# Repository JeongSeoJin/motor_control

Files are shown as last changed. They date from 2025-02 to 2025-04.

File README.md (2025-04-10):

# motor_control

## This repository for motor control and Actuators 
foc control, simplefoc, position control, impedance control and so on

Actuator_V2 folder is complete opensource for proprioceptive actuator. there's a source code for motor control, step files, elements for complete building.

And I am going to make some youtube video for Building Tutorials and specific sources about my own proprioceptive acutator. you can expect it!

Actuator V2 preview is below

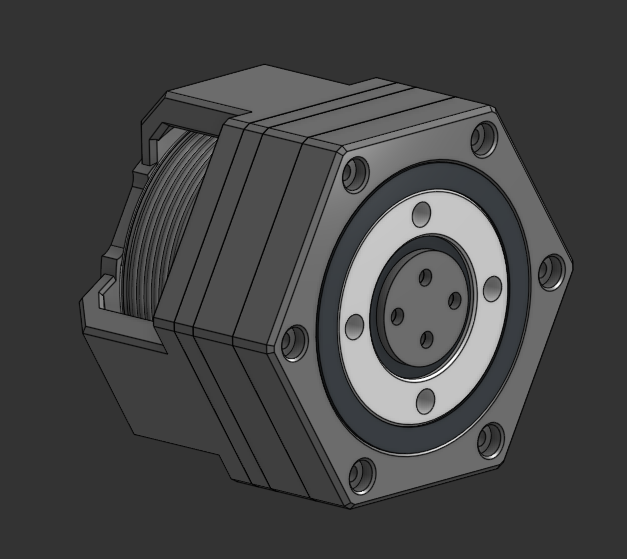
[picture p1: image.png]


And 'drv8302_sunnysky_impedance_arduino' and 'drv8302_sunnysky_impedance_esp' are not actually torque control with current. This is based on voltage systemically. The actual Impedance Control(Torque Control) is 'esp32_current_control_low_side'. This is the Torque Control(Q-axis Current Control) with FOC Algorithm. 

'master_two_drv8302_control_with_CAN', 'slave_two_drv8302_control_with_CAN' and 'two_drv8302_control_with_CAN' are motor control which is 'esp32_current_control_low_side' merged with ACAN library.

By the way, 'TWAI_Simplefoc_Node' is motor control which is 'esp32_current_control_low_side' merged with ESP32-TWAI-CAN library.

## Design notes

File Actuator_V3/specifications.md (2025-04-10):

# Proprioceptive Actuator V2 Specification
---

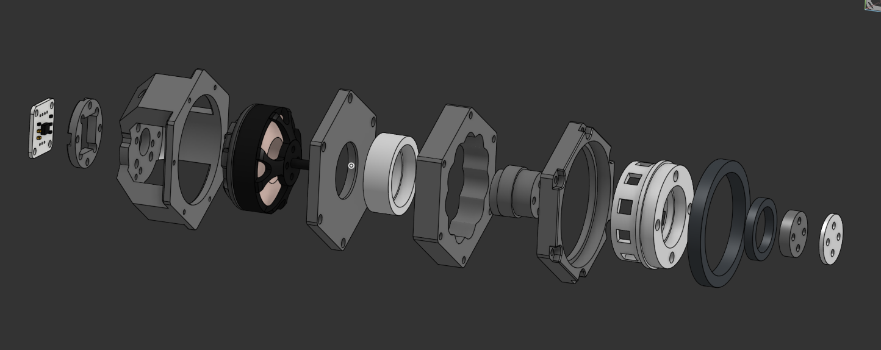
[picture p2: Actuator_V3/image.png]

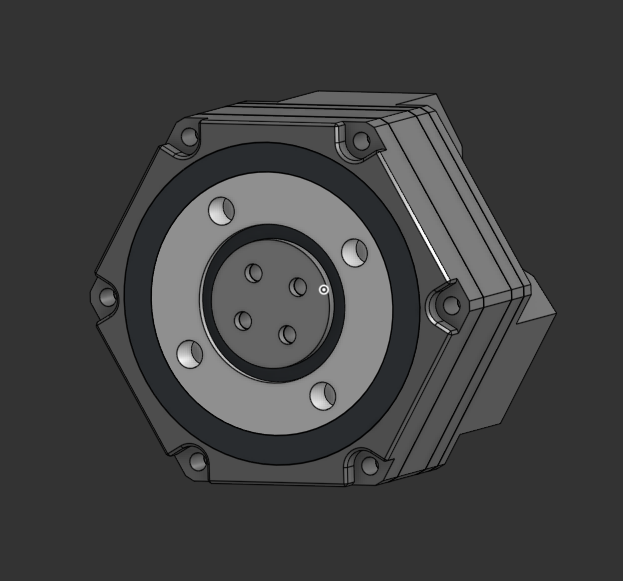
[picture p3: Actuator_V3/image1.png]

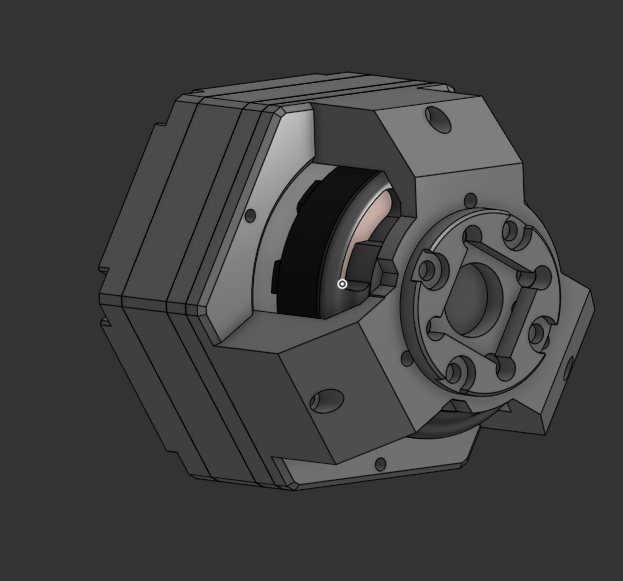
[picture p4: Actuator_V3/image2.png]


## Ball-Element Cycloidal drive actuator V2 (High Performance)
- bldc motor : Gartt ML5210 bldc motor(1EA): [sunnysky x4108s-17 bldc motor](https://ko.aliexpress.com/item/4001297326582.html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)
- motor driver : drv8302(1EA) : [drv8302 driver](https://ko.aliexpress.com/item/4000126430773.html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)
- microcontroller : ESP-wroom-32(1EA) : [ESP-wroom-32](https://ko.aliexpress.com/item/1005007050459447.html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)
- encoder : AS5600(1EA) : [AS5600](https://ko.aliexpress.com/item/1005006502384626.html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)
- For CAN BUS : TJA1051T(1EA) : [TJA1051T](https://ko.aliexpress.com/item/1005007053249619.html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)
- gear box : 3d printed gearbox
- ball-elements(10EA) : [M6x6mm ball-elements](https://ko.aliexpress.com/item/1005003729421711.html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)
- M3x30mm bolts(4EA) : [M3x30mm bolts](https://ko.aliexpress.com/item/1005005879037174.html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)
- M3x20mm bolts(6EA) : [M3x20mm bolts](https://ko.aliexpress.com/item/1005005879037174.html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)
- M2x10mm bolts(6EA) : [M2x10mm bolts]()
- M2x3mm insert nuts(6EA) : [M2x3mm insert nuts](https://ko.aliexpress.com/item/1005004870993068.html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)
- M3x3mm insert nuts(6EA) : [M3x3mm insert nuts](https://ko.aliexpress.com/item/1005004870993068.html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)
- M3x6mm insert nuts(6EA) : [M3x6mm insert nuts](https://ko.aliexpress.com/item/1005004870993068.html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)
- 20x27x4 bearings(3EA) : [20x27x4 bearings](https://ko.aliexpress.com/item/1005006822777675.html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)
- 45x55x6mm bearings(1EA) : [45x55x6mm bearings](https://ko.aliexpress.com/item/4000909605390.html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)

you can see more specific code at [simplefoc documents](https://docs.simplefoc.com/code)

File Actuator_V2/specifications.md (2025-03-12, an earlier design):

# Proprioceptive Actuator V2 Specification
---

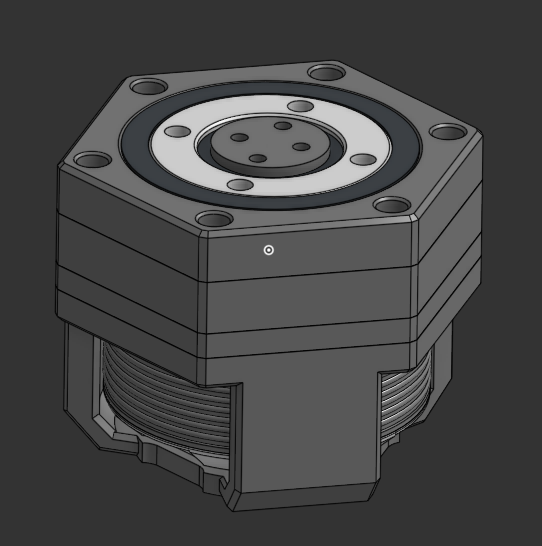
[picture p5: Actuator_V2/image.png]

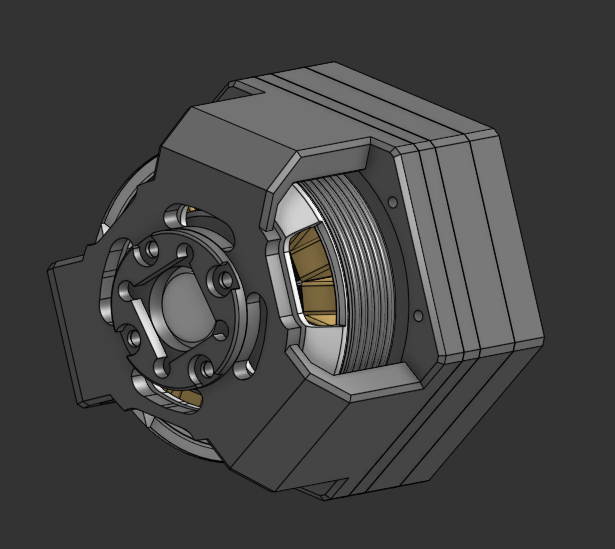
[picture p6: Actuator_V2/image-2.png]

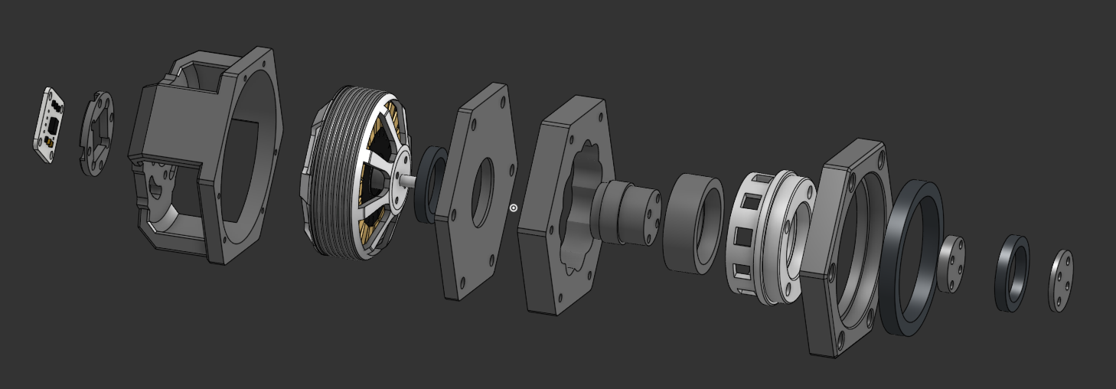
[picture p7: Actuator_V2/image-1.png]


## Ball-Element Cycloidal drive actuator V2 (High Performance)
- bldc motor : Gartt ML5210 bldc motor(1EA): [gartt-ML5210 motor](https://ko.aliexpress.com/item/4001297326582.html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)
- motor driver : drv8302(1EA) : [drv8302 driver](https://ko.aliexpress.com/item/4000126430773.html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)
- microcontroller : ESP-wroom-32(1EA) : [ESP-wroom-32](https://ko.aliexpress.com/item/1005007050459447.html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)
- encoder : AS5600(1EA) : [AS5600](https://ko.aliexpress.com/item/1005006502384626.html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)
- For CAN BUS : TJA1051T(1EA) : [TJA1051T](https://ko.aliexpress.com/item/1005007053249619.html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)
- gear box : 3d printed gearbox
- ball-elements(10EA) : [M6x6mm ball-elements](https://ko.aliexpress.com/item/1005003729421711.html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)
- M3x30mm bolts(4EA) : [M3x30mm bolts](https://ko.aliexpress.com/item/1005005879037174.html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)
- M3x20mm bolts(6EA) : [M3x20mm bolts](https://ko.aliexpress.com/item/1005005879037174.html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)
- M2x10mm bolts(6EA) : [M2x10mm bolts]()
- M2x3mm insert nuts(6EA) : [M2x3mm insert nuts](https://ko.aliexpress.com/item/1005004870993068.html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)
- M3x3mm insert nuts(6EA) : [M3x3mm insert nuts](https://ko.aliexpress.com/item/1005004870993068.html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)
- M3x6mm insert nuts(6EA) : [M3x6mm insert nuts](https://ko.aliexpress.com/item/1005004870993068.html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)
- 20x27x4 bearings(3EA) : [20x27x4 bearings](https://ko.aliexpress.com/item/1005006822777675.html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)
- 45x55x6mm bearings(1EA) : [45x55x6mm bearings](https://ko.aliexpress.com/item/4000909605390.html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)

you can see more specific code at [simplefoc documents](https://docs.simplefoc.com/code)

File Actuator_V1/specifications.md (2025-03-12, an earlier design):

# Actuator V1 Specification
---

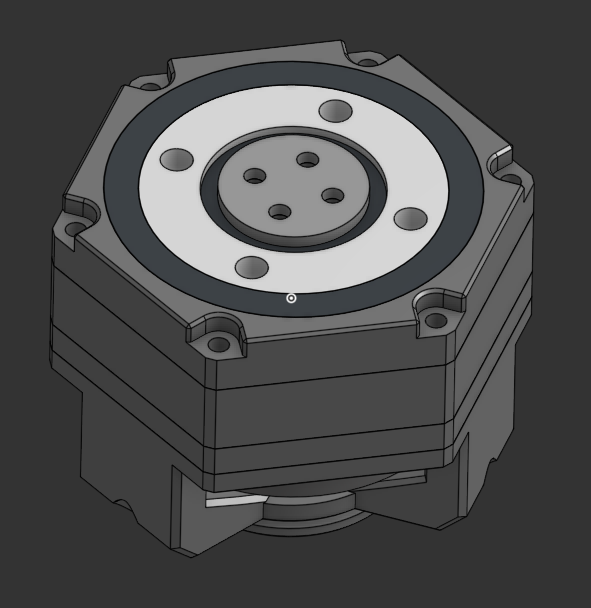
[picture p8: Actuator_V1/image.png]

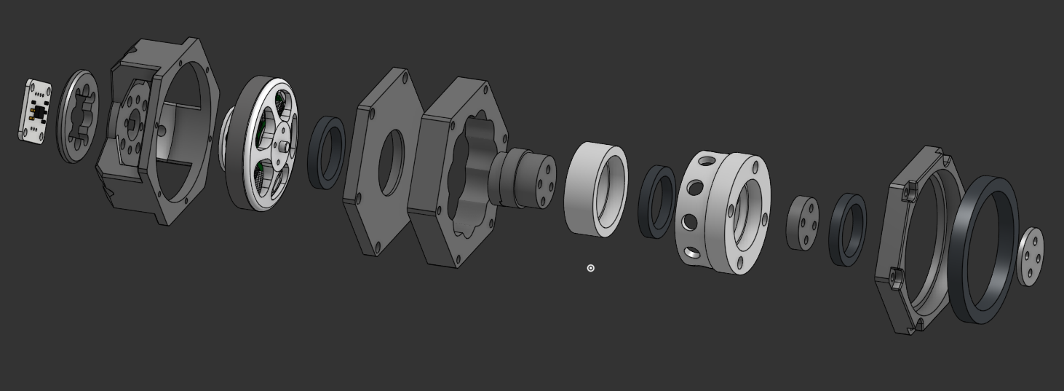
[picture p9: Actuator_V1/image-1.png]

## Ball-Element Cycloidal drive actuator V1
- bldc motor : 5010 bldc motor : [5010 bldc motor](https://ko.aliexpress.com/item/32479766898.html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)
- motor driver : simplefoc v2 : [simplefoc v2](https://simplefoc.com/simplefoc_shield_product)
- microcontroller : arduino uno
- encoder : AS5600 : [AS5600](https://ko.aliexpress.com/item/1005006502384626.html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)
- For CAN BUS : None
- gear box : 3d printed gearbox

you can see more specific code at [simplefoc documents](https://docs.simplefoc.com/code)

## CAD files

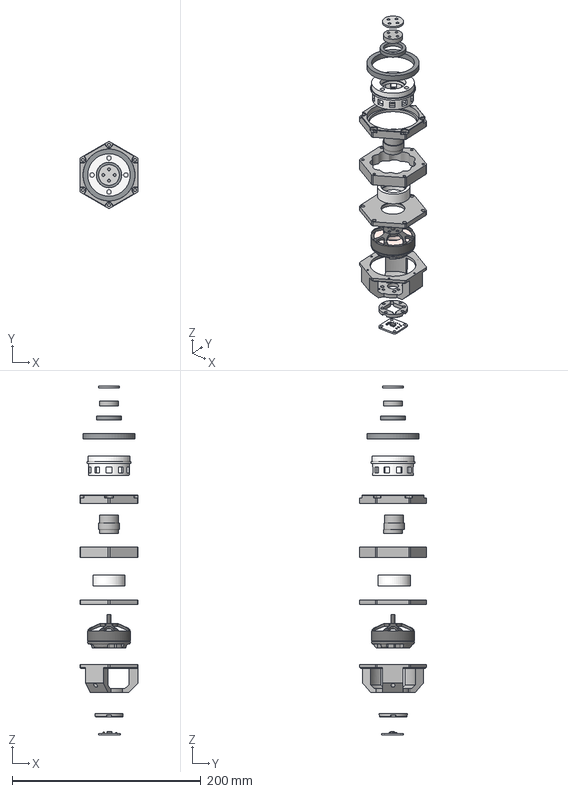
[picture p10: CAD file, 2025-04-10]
Actuator_V3/Actuator_V3_assembly_file.step
62.0 x 70.6 x 370.2 mm
motor_cover
body_middle
Rotor
body_bottom
cam_middle
cam_cover
body_top
AS5600 v1
Stator
bearing_huge
cam_bottom
bearing
wave_generator
separator
Coils

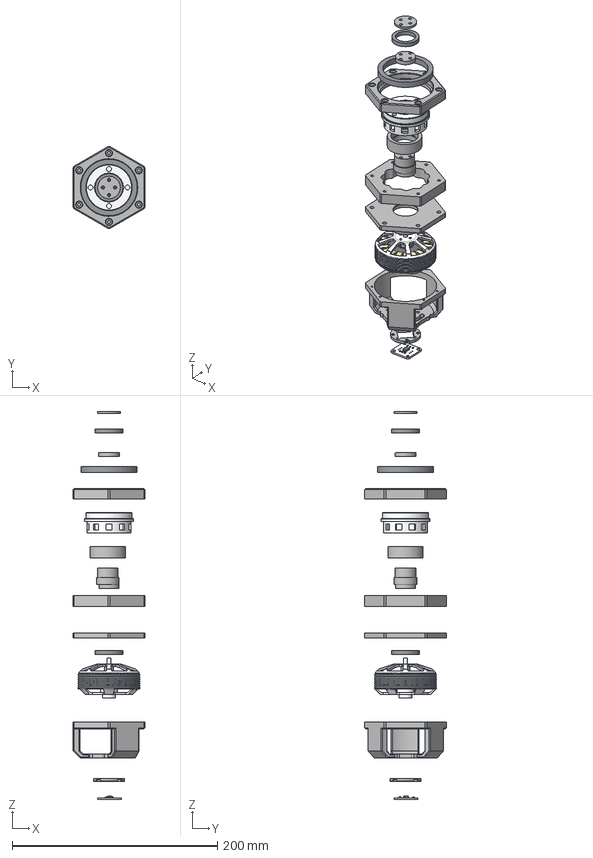
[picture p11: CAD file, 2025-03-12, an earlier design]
Actuator_V2/Actuator_V2_assembly_file.step
70.0 x 79.8 x 377.9 mm
bearing_huge
bearing x 2
mount
cam_bottom
stator
rotor
cam_middle
body_middle
bldc_cover
AS5600 v1
cam_cover
wave_generator
body_bottom
body_top
separator

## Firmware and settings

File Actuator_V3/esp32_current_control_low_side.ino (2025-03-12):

/**
 * 위치 기반 토크 제어 (전류제어 FOC) 예시 코드
 * 
 * [개념]
 *  - 모터의 현재 각도(shaft_angle, [rad])와 목표 각도(theta_desired, [rad])를 비교해
 *    오차(angleError)를 구한다.
 *  - 오차 * Kp ([A/rad]) = 토크 지령 전류(I_q_ref, [A])를 계산한다.
 *  - SimpleFOC는 FOC Current 모드(TorqueControlType::foc_current)에서 이 전류를
 *    실제로 모터의 q축 전류(I_q)로 만들기 위해 PWM을 제어한다.
 * 
 *  => motor.target = I_q_ref (단위: [A])
 *  => 실제 토크 T [N·m] = Kt [N·m/A] × I_q [A]
 */

// This source code is for a proprioceptive actuator v2. torque sensing using q-axis current sensing

#include <SimpleFOC.h>  // SimpleFOC 라이브러리
#include <math.h>

// ============================ 핀 매핑 설정 ============================
// DRV8302 보드 핀 연결 (기본 예시)
#define INH_A    14     // 하이사이드 PWM A
#define INH_B    27     // 하이사이드 PWM B
#define INH_C    26     // 하이사이드 PWM C
#define EN_GATE  13     // 드라이버 활성화
#define M_PWM    33     // 3pwm 모드 설정
#define M_OC     25     // 오버커런트 보호
#define OC_ADJ   32     // 오버커런트 조정
#define OC_GAIN  5      // DRV8302 내부 증폭기 게인 선택 핀

// 로사이드 전류 센싱 핀 (ESP32 ADC 핀)
#define IOUTA 4         // ADC2_CH0
#define IOUTB 12        // ADC2_CH5
#define IOUTC 15        // ADC2_CH3

// ============================= 모터, 드라이버, 센서 =============================

// 1) 모터 객체
//  - BLDCMotor( pole_pairs ): pole_pairs = 극수(pole) / 2
//  - 예: 22극 모터 -> pole_pairs=11
BLDCMotor motor = BLDCMotor(11);

// 2) 드라이버 객체
BLDCDriver3PWM driver = BLDCDriver3PWM(INH_A, INH_B, INH_C, EN_GATE);

// 3) 로사이드 전류센싱
//  - 샨트저항: 0.005Ω
//  - 증폭기 게인: 12.22 V/V (DRV8302 내부 증폭 + 외부 회로에 따라 측정)
LowsideCurrentSense cs = LowsideCurrentSense(0.005f, 12.22f, IOUTA, IOUTB, IOUTC);

// 4) 엔코더 (AS5600 I2C 예시)
MagneticSensorI2C encoder = MagneticSensorI2C(AS5600_I2C);

// 5) 시리얼 커맨드 인터페이스
Commander command = Commander(Serial);
// void onMotor(char* cmd) { command.motor(&motor, cmd); }

// ============================= 제어용 전역 변수 =============================
// 목표 각도 [rad]
float theta_desired = 0.0f;  
// 위치 오차 → 전류로 바꿀 때 사용하는 비례이득 Kp [A/rad]
// 예) Kp=1.0 -> 오차 1rad당 q축전류 1A
float Kp = 2.0f; // max : 5.0
float Cd = 0.2f; // max : 0.2
float max_speed = 60.0f;

float Kt = 60 / (2 * PI * 380);

// Commander에서 theta_desired, Kp를 설정하기 위한 함수
void doRefAngle(char* cmd) { command.scalar(&theta_desired, cmd); }
void doKp(char* cmd)       { command.scalar(&Kp, cmd); }
void doCd(char* cmd)       { command.scalar(&Cd, cmd); }

void setup() {
  // ========== 시리얼 초기화 ==========
  Serial.begin(115200);
  // SimpleFOC 디버그 활성화(옵션)
  SimpleFOCDebug::enable(&Serial);

  // ========== 센서 초기화 ==========
  encoder.init();           // I2C 기반 AS5600 초기화
  motor.linkSensor(&encoder);

  // ========== DRV8302 관련 핀 설정 ==========
  pinMode(M_OC, OUTPUT);
  digitalWrite(M_OC, LOW);
  pinMode(M_PWM, OUTPUT);
  digitalWrite(M_PWM, HIGH);
  pinMode(OC_ADJ, OUTPUT);
  digitalWrite(OC_ADJ, HIGH);
  pinMode(OC_GAIN, OUTPUT);
  digitalWrite(OC_GAIN, LOW); // LOW 상태에서 특정 게인 (약 10~12배)

  // ========== 드라이버 설정 ==========
  driver.voltage_power_supply = 30;   // 드라이버 공급전압 [V]
  driver.pwm_frequency = 15000;       // PWM 주파수 [Hz]
  driver.init();
  motor.linkDriver(&driver);

  // ========== 전류센서 설정 ==========
  cs.linkDriver(&driver);
  
  // ========== 모터 기본 파라미터 ==========
  // FOC 정렬 시 사용하는 전압(각도 캘리브레이션)
  motor.voltage_sensor_align = 0.5f; // [V]
  
  // ========== 핵심: 전류제어(FOC) 설정 ==========
  // 1) 토크제어 모드: foc_current => q축 전류를 직접 제어함
  motor.torque_controller = TorqueControlType::foc_current;
  
  // 2) MotionControlType::torque => motor.target = q축전류(A)
  motor.controller = MotionControlType::torque;
  
  // 3) motion_downsample: 속도/각도 루프를 생략하거나 간소화 (여기서는 0.0)
  motor.motion_downsample = 0.0;

  // ========== PID / LPF 설정 (주로 내부 PI 전류 루프) ==========
  // 전류 i_q 제어
  motor.PID_current_q.P  = 0.05f;   // [V/A] (내부 환산 게인)
  motor.PID_current_q.I  = 0.6f; // [V/(A·s)]
  motor.LPF_current_q.Tf = 0.04f;  // [s]

  // 전류 i_d 제어
  motor.PID_current_d.P  = 0.05f;   // [V/A]
  motor.PID_current_d.I  = 0.6f; // [V/(A·s)]
  motor.LPF_current_d.Tf = 0.04f;  // [s]

  // 속도/각도 제어(지금 안씀)도 일단 기본값 설정
  motor.PID_velocity.P  = 0.1f; 
  motor.PID_velocity.I  = 1.7f;  
  motor.LPF_velocity.Tf = 0.001f;
  motor.P_angle.P       = 10.0f;  
  motor.LPF_angle.Tf    = 0.0f;

  // ========== 제한값 ==========
  // 최대 속도 [rad/s] (토크모드이지만 안전 차원)
  motor.velocity_limit = 50.0f; 
  // FOC에서 인가할 전압의 최대치 [V]
  motor.voltage_limit  = 20.0f;  
  // 최대 전류 제한 [A]
  // -> motor.target이 이 값을 초과 못하도록 내부 보호
  motor.current_limit  = 13.0f;   

  // ========== 모니터링 설정 ==========
  motor.useMonitoring(Serial);
  // D축, Q축 전류 모니터링
  motor.monitor_variables = _MON_CURR_Q | _MON_CURR_D; // q가 토크에 관여, D는 0에 가까워져 있어야함. 
  // 출력 주기 : loopFOC()가 n번 실행될 때마다 한번씩 출력
  motor.monitor_downsample = 100;

  // ========== 모터 초기화 ==========
  motor.init();   // 드라이버, 센서 설정에 맞춰 모터구조 초기 설정
  cs.init();      // 전류센싱 초기화
  // DRV8302는 내부적으로 게인이 반전돼있는 경우가 있어 -1 곱
  cs.gain_a *= -1;
  cs.gain_b *= -1;
  cs.gain_c *= -1;
  motor.linkCurrentSense(&cs);

  // ========== FOC align & start ==========
  // 실제 모터에 전압을 인가하여 엔코더 0점 찾고, d/q 축 정렬
  motor.initFOC();

  // ========== Commander (시리얼 명령) ==========
  // command.add('M', onMotor, "motor");
  command.add('R', doRefAngle, "ref angle [rad]");
  command.add('K', doKp, "Kp [A/rad]");
  command.add('C', doCd, "Cd [A/rad]");

  Serial.println(F("FOC Current-based Torque Control (Position-based)"));
  Serial.println(F(" - R: set target angle [rad]"));
  Serial.println(F(" - K: set Kp [A/rad] (proportional gain)"));
  Serial.println(F(" motor.target will be I_q [A] in torque mode.\n"));

  _delay(1000);
}

void loop() {
  // ========== 1) FOC 알고리즘 업데이트 ==========
  //   - 센서 위치 갱신, d/q 전류 측정 및 PID 계산 등
  motor.loopFOC();

  // ========== 2) 위치 오차 계산 ==========
  //   - 엔코더 각도 [rad]
  float theta = motor.shaft_angle;
  float dtheta = motor.shaft_velocity;
  //   - theta_desired [rad], currentAngle [rad]
  // float angleError = theta_desired - currentAngle;  // [rad]

  // ========== 3) 토크 전류 지령 (Iq_ref) 계산 ==========
  //   - Kp [A/rad] * angleError [rad] = Iq_ref [A]
  float Iq_ref = Kp * (theta_desired - theta) -Cd * dtheta;

  // ========== 4) 모터에 q축 전류 지령 전송 ==========
  //   - torque 모드이므로 motor.target = Iq_ref
  //   - motor.target 단위: [A]

  float output_torque = 10 * Kt * motor.current.q;
  // Serial.println(output_torque);
  // Serial.println(motor.current.q); // 실제 q축 전류

  motor.target = Iq_ref; // [A] foc_current제어이기 때문에 target값이 q축 전류이다.

  // ========== 5) FOC 업데이트 (PWM 출력) ==========
  motor.move();

  // ========== 6) 모니터링 ==========
  motor.monitor();

  // ========== 7) 시리얼 명령 처리 ==========
  command.run();
}

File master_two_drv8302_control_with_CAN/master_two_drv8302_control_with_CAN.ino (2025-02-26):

/********************************************************
 * 1) 매크로 설정: 마스터 / 슬레이브 선택
 ********************************************************/
#define IS_MASTER  // <- 주석 해제 시, 이 보드는 마스터(Commander로 파라미터 입력 + CAN 전송)
//#define IS_MASTER  // 주석 처리 시, 슬레이브(직렬 Commander 없음, CAN 수신만)


/********************************************************
 * 2) 헤더 선언
 ********************************************************/
#include <ACAN_ESP32.h>      // CAN 통신 라이브러리
#include <SimpleFOC.h>       // 모터 FOC 라이브러리
#include <math.h>


/********************************************************
 * 3) CAN 통신 관련 상수
 ********************************************************/
// 원하는 CAN 속도 (예시: 500 kbps)
static const uint32_t DESIRED_BIT_RATE = 500UL * 1000UL;

// CAN 메시지 전송 주기를 제어할 수도 있지만
// 여기서는 "파라미터가 바뀔 때" 즉시 전송하는 방식을 시연

// LED 핀 (ESP32 일부 보드는 2번이 내장 LED)
static const int LED_PIN = 2;

/********************************************************
 * 4) SimpleFOC 모터, 드라이버, 센서 설정
 ********************************************************/
// drv8302 + esp-wroom-32
#define INH_A    14     // 하이사이드 PWM A
#define INH_B    27     // 하이사이드 PWM B
#define INH_C    26     // 하이사이드 PWM C
#define EN_GATE  13     // 드라이버 활성화
#define M_PWM    33     // 3pwm 모드 설정
#define M_OC     25     // 오버커런트 보호
#define OC_ADJ   32     // 오버커런트 조정
#define OC_GAIN  5      // DRV8302 내부 증폭기 게인 선택 핀

// 로사이드 전류 센싱 핀 (ESP32 ADC 핀)
#define IOUTA 4         // ADC2_CH0
#define IOUTB 12        // ADC2_CH5
#define IOUTC 15        // ADC2_CH3

BLDCMotor motor(11);                            // Pole pairs=11 예시
BLDCDriver3PWM driver(INH_A, INH_B, INH_C, EN_GATE);
MagneticSensorI2C encoder(AS5600_I2C);
LowsideCurrentSense cs = LowsideCurrentSense(0.005f, 12.22f, IOUTA, IOUTB, IOUTC);

float theta_desired = 0.0f;  
float Kp = 2.0f; // max : 5.0
float Cd = 0.2f; // max : 0.2
float max_speed = 60.0f;
float Kt = 60 / (2 * PI * 380);


/********************************************************
 * 5) Commander: 직렬 명령 파싱 (마스터에서만 사용)
 ********************************************************/
#ifdef IS_MASTER
// #include <SimpleFOCCommander.h>
Commander command = Commander(Serial);

// FOC 모터에 대한 콜백
// void onMotor(char* cmd) { command.motor(&motor, cmd); }
void setVelocityP(char* cmd) { command.scalar(&motor.PID_velocity.P, cmd); }
void setVelocityI(char* cmd) { command.scalar(&motor.PID_velocity.I, cmd); }
#endif

/********************************************************
 * 6) 임피던스 제어용 파라미터
 ********************************************************/
// (필요하면 M_mass, target_position 등 추가 가능)

/********************************************************
 * 7) 전역 변수 / 자료형
 ********************************************************/
// float ↔ byte 변환용 union
union FloatUnion {
  float f;
  uint8_t b[4];
};

// 파라미터 식별자
static const uint8_t PARAM_ID_REF_ANGLE = 0x01;
static const uint8_t PARAM_ID_KSPRING   = 0x02;
static const uint8_t PARAM_ID_CDAMPER   = 0x03;

// CAN ID (파라미터 브로드캐스트용)
static const uint32_t PARAM_CAN_ID = 0x100;

/********************************************************
 * 8) 파라미터 변경 시 CAN 전송 함수 (마스터 전용)
 ********************************************************/
#ifdef IS_MASTER
void sendParamOverCAN(uint8_t paramID, float value) {
  CANMessage txFrame;
  txFrame.id = PARAM_CAN_ID;
  txFrame.len = 5; // [1바이트 paramID + 4바이트 float]

  txFrame.data[0] = paramID; // 어떤 파라미터인지 구분

  FloatUnion fu;
  fu.f = value;
  for (int i = 0; i < 4; i++) {
    txFrame.data[i+1] = fu.b[i]; // ???????????? 갑자기 fu.b는 왜 나온 거지? garbage 값이어야하는데.
    //                               --> 이에 대한 답변 : union은 공용체 멤버들이 동일한 메모리 영역을 공유하기 때문이다.
    //fu.f = value; -> union의 4바이트 메모리 영역이 value의 부동소수점 비트로 채워짐. 
    //그리고 fu.b[i]가 같은 4바이트 구역을 바이트 배열로 해석해 읽어옴.
    //이렇게 사용하는 것 방법은 C언어에서 부동소수점 값을 바이트로 분해하는 전형적인 기법이며, CAN메시지나 시리얼 패킷에
    //float를 담기 위해 이 방식을 사용할 수 있다.
  }

  if (ACAN_ESP32::can.tryToSend(txFrame)) {
    Serial.print("[CAN] Param sent. ID=");
    Serial.print(paramID, HEX); //??? what is HEX
    Serial.print(", value=");
    Serial.println(value);
  } else {
    Serial.println("[CAN] Send error!");
  }

  //paramID를 가진 값이 Commander를 통해 바뀔 때, 즉시 CAN으로 브로드 캐스트 하는 방식이다.
}
#endif

/********************************************************
 * 9) Commander 콜백: ref_angle, K_spring, C_damper
 ********************************************************/
#ifdef IS_MASTER
void doRefAngle(char* cmd) {
  command.scalar(&theta_desired, cmd); // 기존 Commander 방식
  // 변경됐으니 CAN 전송
  sendParamOverCAN(PARAM_ID_REF_ANGLE, theta_desired);
}
void doKp(char* cmd) {
  command.scalar(&Kp, cmd);
  sendParamOverCAN(PARAM_ID_KSPRING, Kp);
}
void doCd(char* cmd) {
  command.scalar(&Cd, cmd);
  sendParamOverCAN(PARAM_ID_CDAMPER, Cd);
}
#endif
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

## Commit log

2025-02-14 Add: drb8302 with esp32
2025-03-05 Add : esp32_current_control_low_side
2025-03-12 Update:Actuator V1
2025-04-10 Add: drone_motor_control, TWAI_Simplefoc_Node Update: esp32_current_control_low_side
2025-04-10 Add:Actuator_V3 Documentation
    [Actuator_V3_assembly_file.step]
